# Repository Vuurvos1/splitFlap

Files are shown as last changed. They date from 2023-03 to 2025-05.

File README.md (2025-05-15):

<h1 align="center">SplitFlap</h1>

<p align="center">
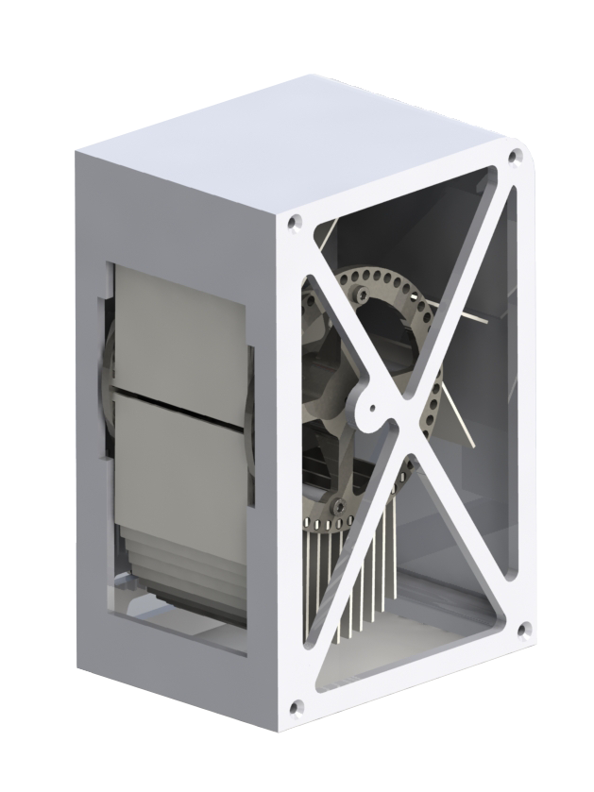
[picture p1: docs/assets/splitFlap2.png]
Split flap module
  
</p>

<p align="center">A modernized split flap display.</p>

## Features

- 50 Flaps per module
- 54mm x 80mm Character size
- Compact 80mm x 160mm x 110mm module size
- 3D printable
- Daisy chained
- Web controllabe

## Dashboard

The display can be controlled through a web dashboard hosted on the controller module.

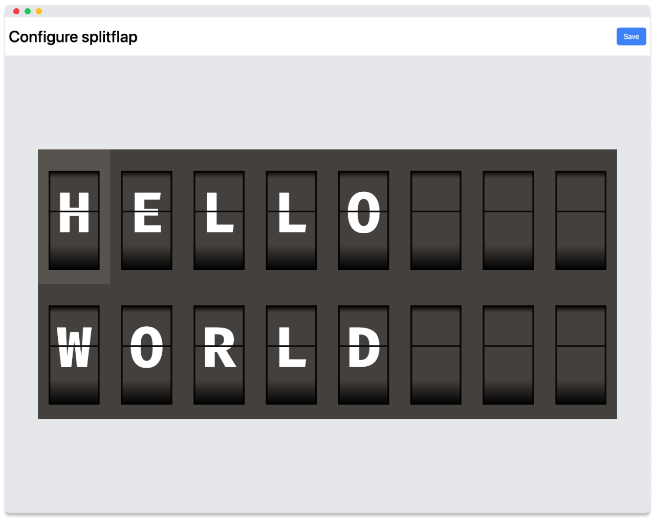
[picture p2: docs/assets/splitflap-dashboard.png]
Dashboard


## Flap Characters

Suggested 50 characters:

```
A B C D E F G H I J K L M N O P Q R S T U V W X Y Z (26)
1 2 3 4 5 6 7 8 9 0 (10)
blank □ full ■ (2)
? ! + - = * ' : , . @ # % € (14)
```

 <!-- $ & ^ ; -->

> [!NOTE]  
> `0 O` and `1 I` can share the same flap

## Materials

- 1x Nema 17 Stepper Motor
- 1x A4988 Stepper Motor Driver (or similar)
- 1x Hall Effect Switch (a TLE4905L or similar)
- 8x M3 Countersunk Screws (for the body)
- 8x M3 Screws (for the barrel)
- 4x M3x18 Screws (to mount the motor)
- 1x M3 Countersunk Screw (for the flap stopper)

### Micro controller

- Esp32
- Arduino pro micro

I am using an Esp32 for the main module, and you can use any other micro controller like a pro micro for the other modules.

### Motor

I originally got dual shafted Nema 17 motors for this project so I could mount the flap barrel on the back side of the motor.

> [!NOTE]  
> You could use any other Nema 17 motor with a reversed D shaft.
> Reversing the shaft can easily be done if you open up the motor and flip the shaft so it sticks out of the "back" of the motor.
> You might need to tweak the motor spacers and use different length screws to mount different motors.

### Driver

- A4988 Stepper Motor Driver

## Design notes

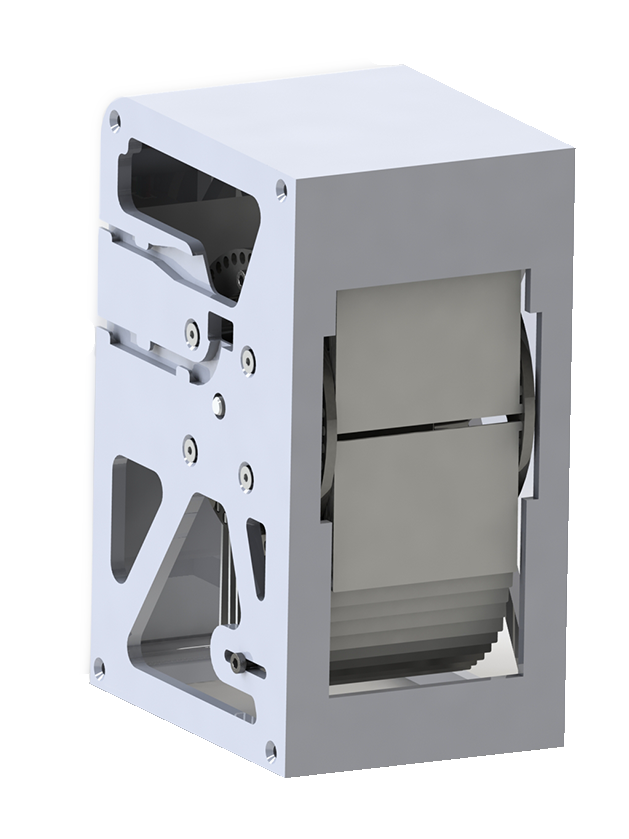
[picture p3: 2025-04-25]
docs/assets/splitFlap1.png

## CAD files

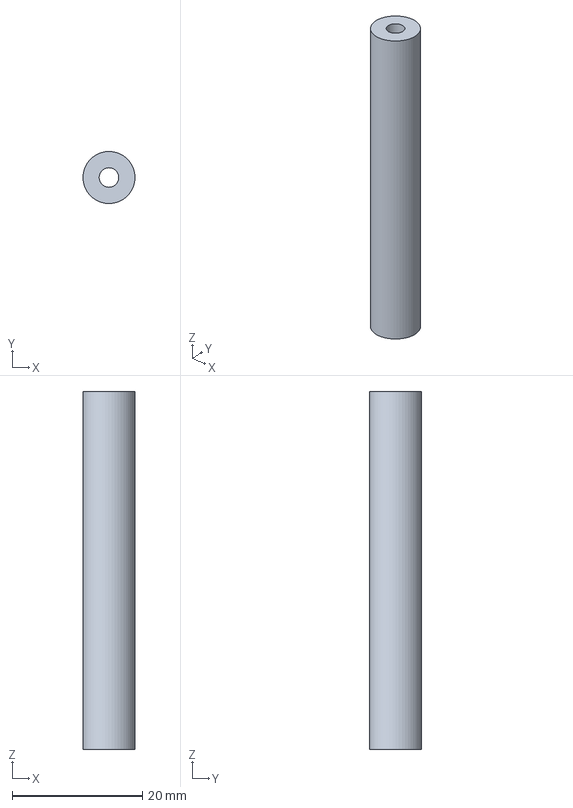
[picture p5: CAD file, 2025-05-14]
cad/barrel/barrelSpacer.FCStd
7.99 x 8.00 x 55.0 mm

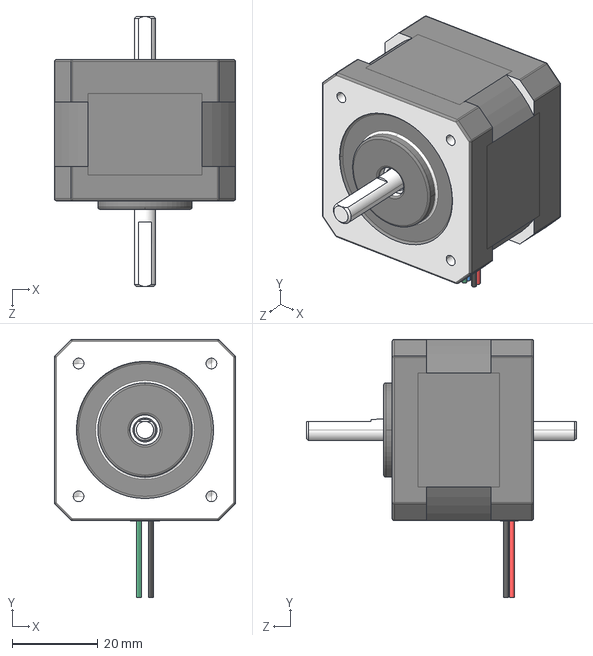
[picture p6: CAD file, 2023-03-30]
cad/hardware/17HS13-0404D.STEP
42.3 x 60.3 x 63.0 mm

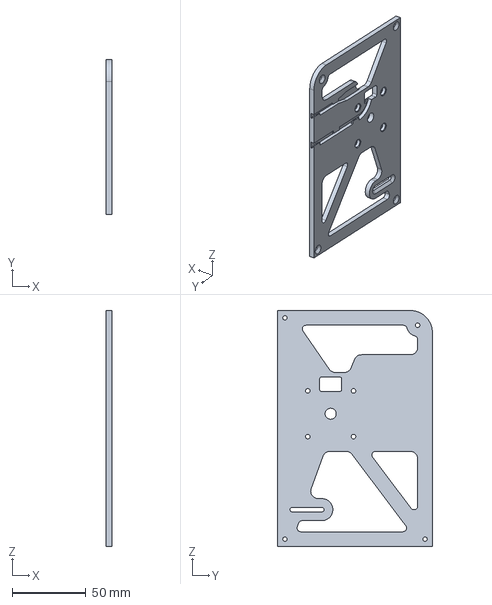
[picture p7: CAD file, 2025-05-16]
cad/sideMotor.FCStd
4.00 x 105.0 x 160.0 mm

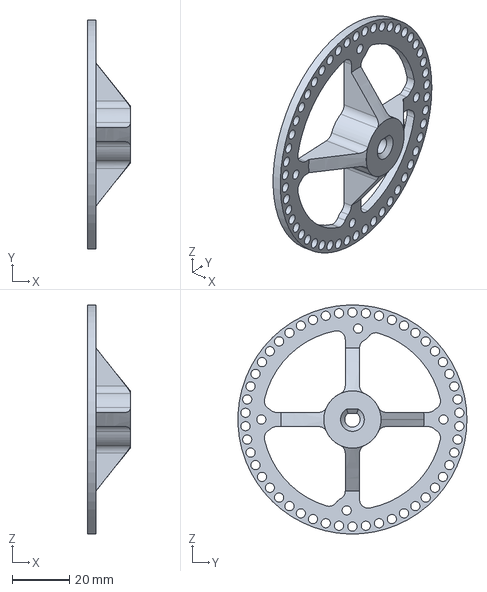
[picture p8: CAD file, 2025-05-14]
cad/barrel/barrelMount.FCStd
15.0 x 79.9 x 80.0 mm

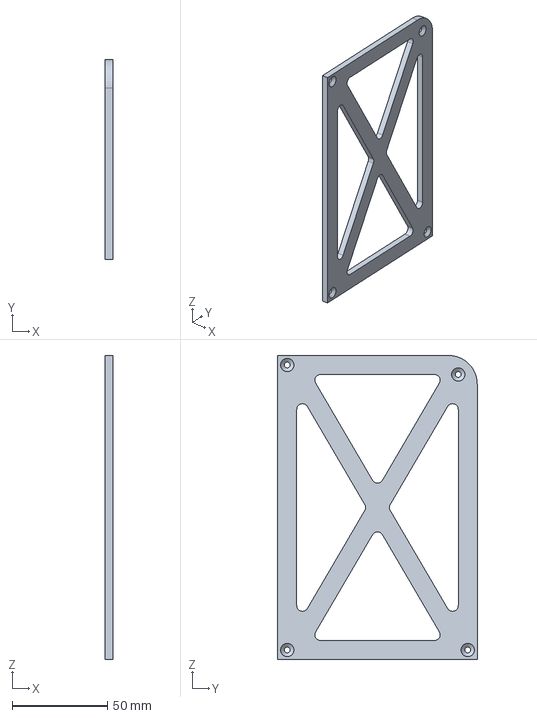
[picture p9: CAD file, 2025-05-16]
cad/sideLeft.FCStd
4.00 x 105.0 x 160.0 mm

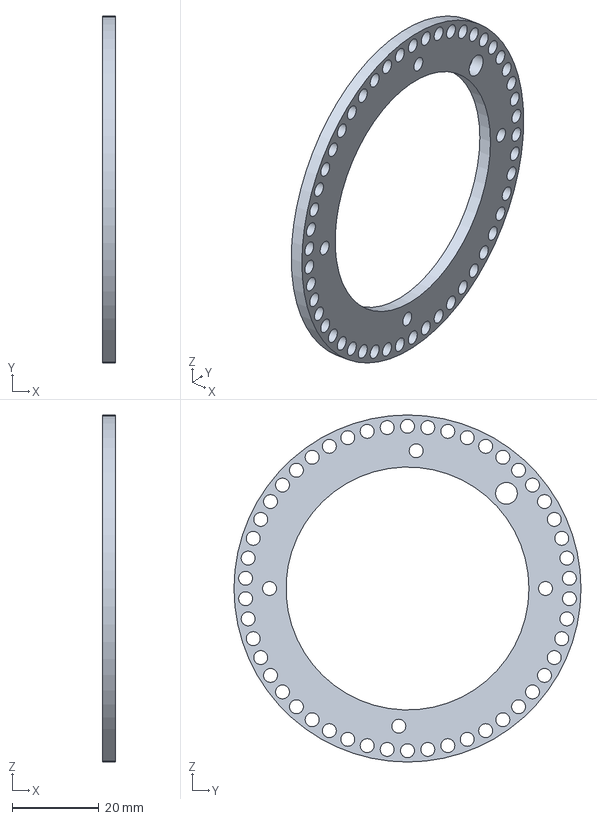
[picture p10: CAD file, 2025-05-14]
cad/barrel/barrelSideOpen.FCStd
3.00 x 80.0 x 80.0 mm

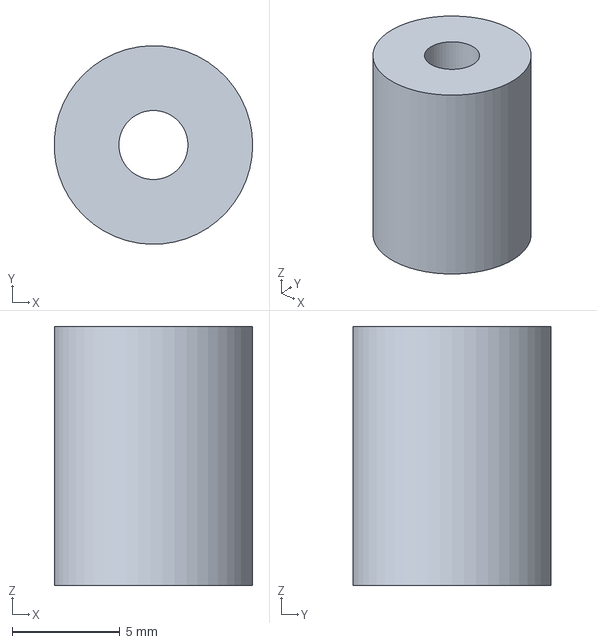
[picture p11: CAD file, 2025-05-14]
cad/motorSpacer.FCStd
9.19 x 9.20 x 12.0 mm

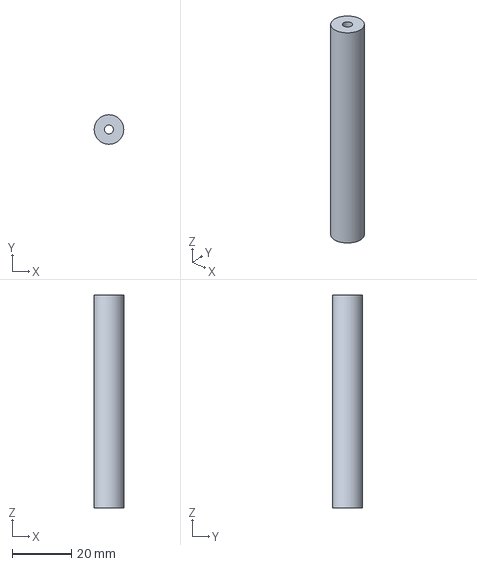
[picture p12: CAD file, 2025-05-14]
cad/bodySpacer.FCStd
9.99 x 10.00 x 72.0 mm

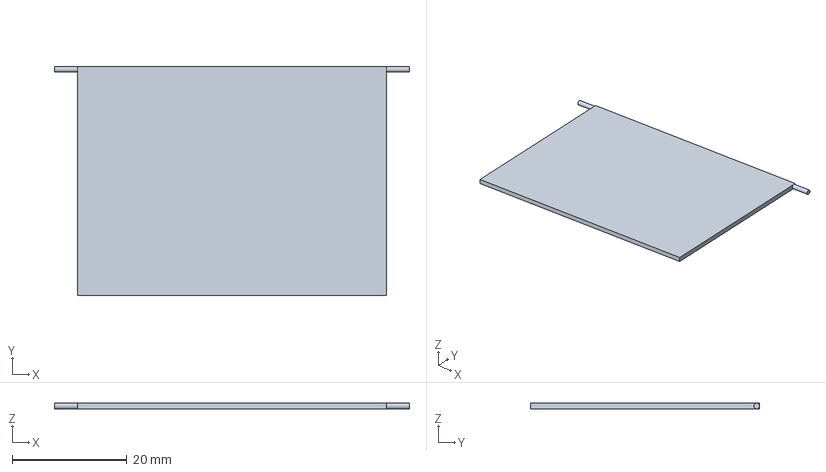
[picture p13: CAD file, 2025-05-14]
cad/roundFlap.FCStd
62.0 x 40.0 x 1.00 mm

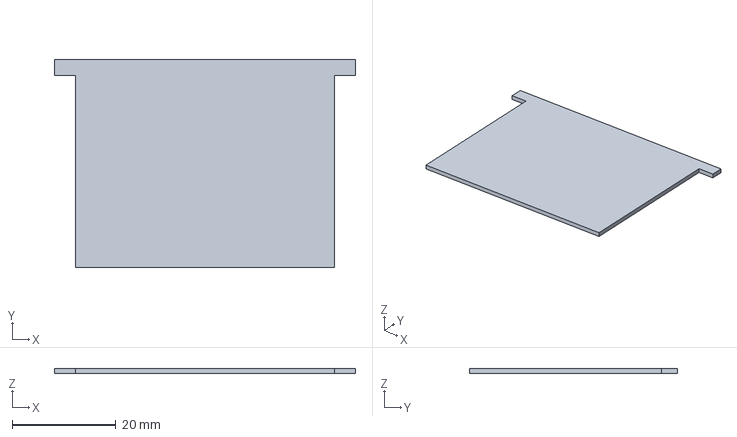
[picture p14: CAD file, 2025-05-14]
cad/flap.FCStd
58.0 x 40.0 x 1.00 mm

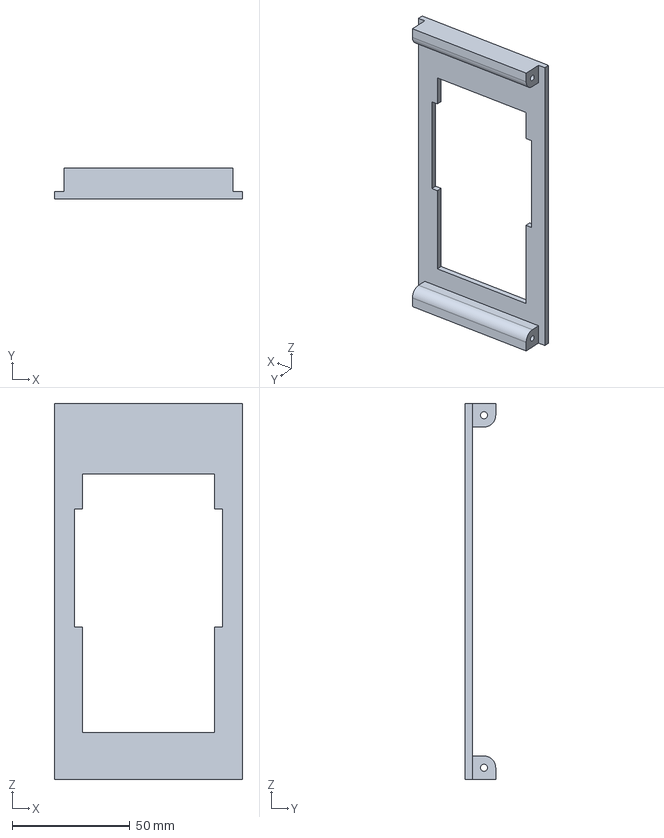
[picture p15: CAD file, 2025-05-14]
cad/front.FCStd
80.0 x 13.0 x 160.0 mm

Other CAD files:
cad/splitflap.FCStd
cad/barrel/barrel.FCStd
cad/hardware/17HS13-0404D.FCStd

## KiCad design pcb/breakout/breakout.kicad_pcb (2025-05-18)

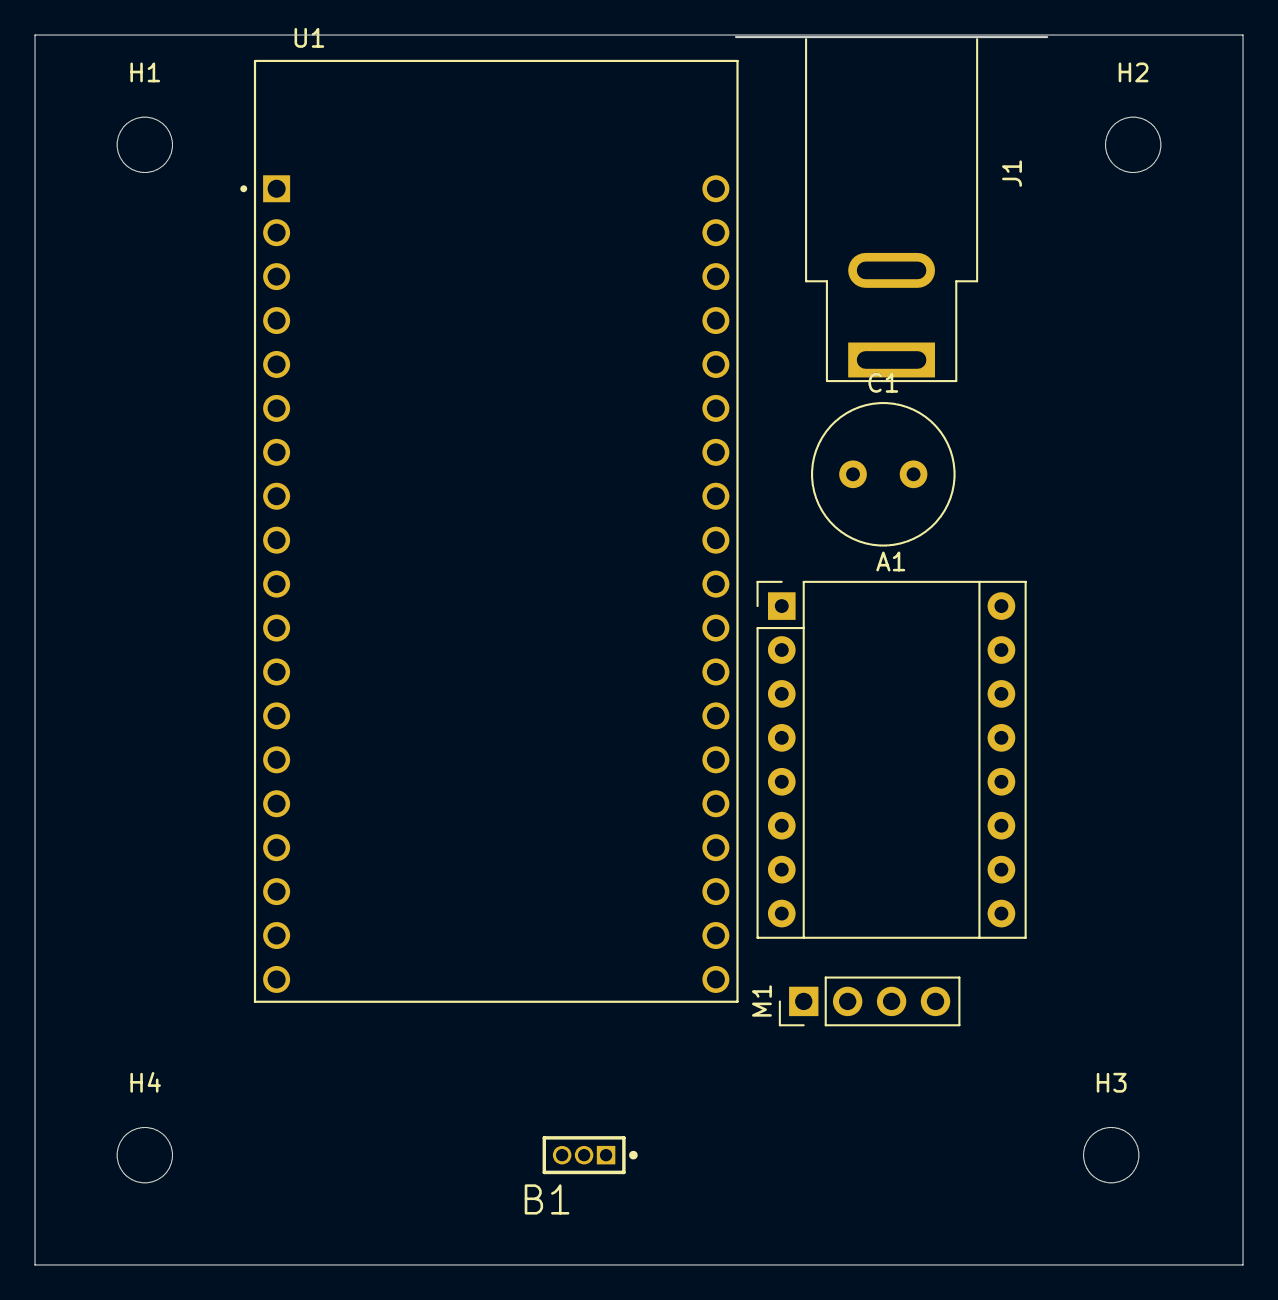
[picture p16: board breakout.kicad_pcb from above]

Board: 2 copper layers, 69.9 x 71.1 mm, 10 parts (0 on the bottom side), 12 nets, no tracks yet.

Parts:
A1: Pololu_Breakout_A4988; Pololu_Breakout-16_15.2x20.3mm
B1: TLE4905L; IFX-PG-SSO-3-2
C1: 100uF; C_Radial_D8.0mm_H11.5mm_P3.50mm
H1, H2, H3, H4: MountingHole; MountingHole_3.2mm_M3
J1: Barrel_Jack; BarrelJack_SwitchcraftConxall_RAPC10U_Horizontal
M1: Stepper_Motor_bipolar; PinHeader_1x04_P2.54mm_Vertical
U1: ESP32-DEVKITC-32D; MODULE_ESP32-DEVKITC-32D

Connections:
+5V: A1.2 (VDD), A1.10 (MS1), A1.11 (MS2), A1.12 (MS3), B1.1 (VS)
+12V: A1.8 (VMOT), C1.1, J1.1
<NO NET>: A1.1 (GND), A1.7 (GND), C1.2, J1.2
D15: B1.3 (Q), U1.J3-16 (IO15)
D18: A1.15 (STEP), U1.J3-9 (IO18)
D19: A1.16 (DIR), U1.J3-8 (IO19)
GND: B1.2 (GND), U1.J2-14 (GND1), U1.J3-1 (GND3), U1.J3-7 (GND2)
unnamed: A1.4 (1A), M1.1
unnamed: A1.3 (1B), M1.2 (-)
unnamed: A1.5 (2A), M1.3
unnamed: A1.6 (2B), M1.4
unnamed: A1.13 (~RESET), A1.14 (~SLEEP)

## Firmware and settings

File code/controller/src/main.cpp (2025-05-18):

#include <Arduino.h>
#include <config.h>
#include <HardwareSerial.h>

#include <WiFi.h>
#include <WebServer.h>
#include <ESPmDNS.h>
#include <LittleFS.h>

#include <SplitFlap.h>
#include <utils.h>

#define TXD1 19
#define RXD1 21

// Use Serial1 for UART communication
HardwareSerial mySerial(1);

WebServer server(80);

// defines pins
#define STEP_PIN 16
#define DIR_PIN 17
#define HALL_PIN 15

SplitFlap splitFlap(STEP_PIN, DIR_PIN, HALL_PIN);

String getContentType(String filename)
{
  if (filename.endsWith(".html"))
    return "text/html";
  else if (filename.endsWith(".css"))
    return "text/css";
  else if (filename.endsWith(".js"))
    return "application/javascript";
  else if (filename.endsWith(".json"))
    return "application/json";
  else if (filename.endsWith(".png"))
    return "image/png";
  else if (filename.endsWith(".jpg"))
    return "image/jpeg";
  else if (filename.endsWith(".ico"))
    return "image/x-icon";
  else if (filename.endsWith(".svg"))
    return "image/svg+xml";
  else if (filename.endsWith(".woff2"))
    return "font/woff2";
  else if (filename.endsWith(".woff"))
    return "font/woff";
  else if (filename.endsWith(".ttf"))
    return "font/ttf";
  else if (filename.endsWith(".mp3"))
    return "audio/mpeg";
  else if (filename.endsWith(".mp4"))
    return "video/mp4";
  return "application/octet-stream";
}

bool handleFileRead(String path)
{
  if (path.endsWith("/"))
    path += "index.html";

  String contentType = getContentType(path);

  if (LittleFS.exists(path))
  {
    File file = LittleFS.open(path, "r");
    server.streamFile(file, contentType);
    file.close();
    return true;
  }
  return false;
}

void handleNotFound()
{
  if (!handleFileRead(server.uri()))
  {
    {
      // Fall back to index.html for client-side routing
      handleFileRead("/index.html");
    }

    // server.send(404, "text/plain", "Not found");
  }
}

void handleCharacter()
{
  if (server.hasArg("c"))
  {
    char c = server.arg("c")[0];
    splitFlap.setCharacter(c);
    server.send(200, "text/plain", "OK");
    return;
  }

  server.send(400, "text/plain", "Bad request");
}

void handleFlaps()
{
  if (server.hasArg("f"))
  {
    int f = server.arg("f").toInt();
    splitFlap.setFlap(f);
    server.send(200, "text/plain", "OK");
    return;
  }

  server.send(400, "text/plain", "Bad request");
}

void handleSplitflap()
{
  if (server.method() != HTTP_POST)
  {
    server.send(405, "text/plain", "Method Not Allowed");
    return;
  }

  String body = server.arg("plain");

  // Simple validation - must start with [ and end with ]
  if (body[0] != '[' || body[body.length() - 1] != ']')
  {
    server.send(400, "text/plain", "Invalid array format");
    return;
  }

  // Remove the brackets
  body = body.substring(1, body.length() - 1);

  std::vector<uint8_t> data;

  // Split string into numbers and add to data vector
  int start = 0;
  while (true)
  {
    int end = body.indexOf(',', start);
    bool isLast = (end == -1);
    if (isLast)
    {
      end = body.length();
    }

    String numStr = body.substring(start, end);
    numStr.trim();
    if (numStr.length() > 0)
    {
      data.push_back(static_cast<uint8_t>(numStr.toInt()));
    }

    if (isLast)
      break;
    start = end + 1;
  }

  // print the data
  Serial.print("Data: ");
  for (uint8_t byte : data)
  {
    Serial.print(byte);
    Serial.print(" ");
  }
  Serial.println();

  // set splitflap to the first data value
  splitFlap.setFlap(data[0]);
  data.erase(data.begin());

  // pass the rest of the data to the splitflap
  auto packet = createPacket(data);
  mySerial.write(packet.data(), packet.size());

  server.send(200, "text/plain", "OK");
}

void setup()
{
  Serial.begin(115200);
  mySerial.begin(9600, SERIAL_8N1, RXD1, TXD1); // UART setup

  Serial.println("ESP32 UART Transmitter");

  while (!Serial)
    ;

  if (!LittleFS.begin(true))
  {
    Serial.println("An error occurred while mounting LittleFS");
  }

  splitFlap.init();
  splitFlap.home();

  WiFi.begin(WIFI_SSID, WIFI_PASSWORD);
  Serial.println("Establishing connection to WiFi");

  while (WiFi.status() != WL_CONNECTED)
  {
    delay(1000);
    Serial.print(".");
  }
  Serial.print("Connected to network with IP address: ");
  Serial.println(WiFi.localIP());

  // Initialize mDNS
  if (!MDNS.begin("splitflap"))
  { // Set the hostname to "splitflap.local"
    Serial.println("Error setting up MDNS responder!");
    while (1)
    {
      delay(1000);
    }
  }
  Serial.println("mDNS responder started");

  // server.on("/character", handleCharacter);
  server.on("/api/splitflap", handleSplitflap);
  server.on("/flaps", handleFlaps);
  server.onNotFound(handleNotFound);

  server.begin();
  Serial.println("HTTP server started");
}

void loop()
{
  splitFlap.update();
  server.handleClient();
}

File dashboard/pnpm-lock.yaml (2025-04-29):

lockfileVersion: '9.0'

settings:
  autoInstallPeers: true
  excludeLinksFromLockfile: false

importers:

  .:
    dependencies:
      '@fontsource/fira-mono':
        specifier: ^5.2.5
        version: 5.2.5
      '@unocss/reset':
        specifier: 66.1.0-beta.12
        version: 66.1.0-beta.12
    devDependencies:
      '@eslint/compat':
        specifier: ^1.2.5
        version: 1.2.8(eslint@9.25.1(jiti@2.4.2))
      '@eslint/js':
        specifier: ^9.18.0
        version: 9.25.1
      '@sveltejs/adapter-auto':
        specifier: ^6.0.0
        version: 6.0.0(@sveltejs/kit@2.20.7(@sveltejs/vite-plugin-svelte@5.0.3(svelte@5.28.2)(vite@6.3.3(jiti@2.4.2)))(svelte@5.28.2)(vite@6.3.3(jiti@2.4.2)))
      '@sveltejs/adapter-static':
        specifier: ^3.0.8
        version: 3.0.8(@sveltejs/kit@2.20.7(@sveltejs/vite-plugin-svelte@5.0.3(svelte@5.28.2)(vite@6.3.3(jiti@2.4.2)))(svelte@5.28.2)(vite@6.3.3(jiti@2.4.2)))
      '@sveltejs/kit':
        specifier: ^2.16.0
        version: 2.20.7(@sveltejs/vite-plugin-svelte@5.0.3(svelte@5.28.2)(vite@6.3.3(jiti@2.4.2)))(svelte@5.28.2)(vite@6.3.3(jiti@2.4.2))
      '@sveltejs/vite-plugin-svelte':
        specifier: ^5.0.0
        version: 5.0.3(svelte@5.28.2)(vite@6.3.3(jiti@2.4.2))
      '@unocss/extractor-svelte':
        specifier: 66.1.0-beta.12
        version: 66.1.0-beta.12
      eslint:
        specifier: ^9.18.0
        version: 9.25.1(jiti@2.4.2)
      eslint-config-prettier:
        specifier: ^10.0.1
        version: 10.1.2(eslint@9.25.1(jiti@2.4.2))
      eslint-plugin-svelte:
        specifier: ^3.0.0
        version: 3.5.1(eslint@9.25.1(jiti@2.4.2))(svelte@5.28.2)
      globals:
        specifier: ^16.0.0
        version: 16.0.0
      prettier:
        specifier: ^3.4.2
        version: 3.5.3
      prettier-plugin-svelte:
        specifier: ^3.3.3
        version: 3.3.3(prettier@3.5.3)(svelte@5.28.2)
      svelte:
        specifier: ^5.0.0
        version: 5.28.2
      svelte-check:
        specifier: ^4.0.0
        version: 4.1.6(picomatch@4.0.2)(svelte@5.28.2)(typescript@5.8.3)
      typescript:
        specifier: ^5.0.0
        version: 5.8.3
      typescript-eslint:
        specifier: ^8.20.0
        version: 8.31.0(eslint@9.25.1(jiti@2.4.2))(typescript@5.8.3)
      unocss:
        specifier: 66.1.0-beta.12
        version: 66.1.0-beta.12(postcss@8.5.3)(vite@6.3.3(jiti@2.4.2))(vue@3.5.13(typescript@5.8.3))
      vite:
        specifier: ^6.2.6
        version: 6.3.3(jiti@2.4.2)

packages:

  '@ampproject/remapping@2.3.0':
    resolution: {integrity: sha512-30iZtAPgz+LTIYoeivqYo853f02jBYSd5uGnGpkFV0M3xOt9aN73erkgYAmZU43x4VfqcnLxW9Kpg3R5LC4YYw==}
    engines: {node: '>=6.0.0'}

  '@antfu/install-pkg@1.0.0':
    resolution: {integrity: sha512-xvX6P/lo1B3ej0OsaErAjqgFYzYVcJpamjLAFLYh9vRJngBrMoUG7aVnrGTeqM7yxbyTD5p3F2+0/QUEh8Vzhw==}

  '@antfu/utils@8.1.1':
    resolution: {integrity: sha512-Mex9nXf9vR6AhcXmMrlz/HVgYYZpVGJ6YlPgwl7UnaFpnshXs6EK/oa5Gpf3CzENMjkvEx2tQtntGnb7UtSTOQ==}

  '@babel/helper-string-parser@7.25.9':
    resolution: {integrity: sha512-4A/SCr/2KLd5jrtOMFzaKjVtAei3+2r/NChoBNoZ3EyP/+GlhoaEGoWOZUmFmoITP7zOJyHIMm+DYRd8o3PvHA==}
    engines: {node: '>=6.9.0'}

  '@babel/helper-validator-identifier@7.25.9':
    resolution: {integrity: sha512-Ed61U6XJc3CVRfkERJWDz4dJwKe7iLmmJsbOGu9wSloNSFttHV0I8g6UAgb7qnK5ly5bGLPd4oXZlxCdANBOWQ==}
    engines: {node: '>=6.9.0'}

  '@babel/parser@7.27.0':
    resolution: {integrity: sha512-iaepho73/2Pz7w2eMS0Q5f83+0RKI7i4xmiYeBmDzfRVbQtTOG7Ts0S4HzJVsTMGI9keU8rNfuZr8DKfSt7Yyg==}
    engines: {node: '>=6.0.0'}
    hasBin: true

  '@babel/types@7.27.0':
    resolution: {integrity: sha512-H45s8fVLYjbhFH62dIJ3WtmJ6RSPt/3DRO0ZcT2SUiYiQyz3BLVb9ADEnLl91m74aQPS3AzzeajZHYOalWe3bg==}
    engines: {node: '>=6.9.0'}

  '@esbuild/aix-ppc64@0.25.3':
    resolution: {integrity: sha512-W8bFfPA8DowP8l//sxjJLSLkD8iEjMc7cBVyP+u4cEv9sM7mdUCkgsj+t0n/BWPFtv7WWCN5Yzj0N6FJNUUqBQ==}
    engines: {node: '>=18'}
    cpu: [ppc64]
    os: [aix]

  '@esbuild/android-arm64@0.25.3':
    resolution: {integrity: sha512-XelR6MzjlZuBM4f5z2IQHK6LkK34Cvv6Rj2EntER3lwCBFdg6h2lKbtRjpTTsdEjD/WSe1q8UyPBXP1x3i/wYQ==}
    engines: {node: '>=18'}
    cpu: [arm64]
    os: [android]

  '@esbuild/android-arm@0.25.3':
    resolution: {integrity: sha512-PuwVXbnP87Tcff5I9ngV0lmiSu40xw1At6i3GsU77U7cjDDB4s0X2cyFuBiDa1SBk9DnvWwnGvVaGBqoFWPb7A==}
    engines: {node: '>=18'}
    cpu: [arm]
    os: [android]

  '@esbuild/android-x64@0.25.3':
    resolution: {integrity: sha512-ogtTpYHT/g1GWS/zKM0cc/tIebFjm1F9Aw1boQ2Y0eUQ+J89d0jFY//s9ei9jVIlkYi8AfOjiixcLJSGNSOAdQ==}
    engines: {node: '>=18'}
    cpu: [x64]
    os: [android]

  '@esbuild/darwin-arm64@0.25.3':
    resolution: {integrity: sha512-eESK5yfPNTqpAmDfFWNsOhmIOaQA59tAcF/EfYvo5/QWQCzXn5iUSOnqt3ra3UdzBv073ykTtmeLJZGt3HhA+w==}
    engines: {node: '>=18'}
    cpu: [arm64]
    os: [darwin]
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

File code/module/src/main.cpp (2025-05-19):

#include <Arduino.h>
#include "utils.h"
#include <vector>
#include "SplitFlap.h"

#define TXD1 19
#define RXD1 21

// defines pins
#define STEP_PIN 16
#define DIR_PIN 17
#define HALL_PIN 15

SplitFlap splitFlap(STEP_PIN, DIR_PIN, HALL_PIN);

// Use Serial1 for UART communication
HardwareSerial mySerial(2);

bool readingPacket = false;

void handleMyByte(uint8_t byte)
{
  Serial.println("Received byte: " + String(byte));
  splitFlap.setFlap(byte);
}

void setup()
{
  Serial.begin(115200);
  mySerial.begin(9600, SERIAL_8N1, RXD1, TXD1); // UART setup

  splitFlap.init();
  splitFlap.home();

  Serial.println("Module started");
}

uint8_t flapIndex = 40;

void loop()
{
  splitFlap.update();

  // Check if data is available to read
  if (mySerial.available())
  {
    uint8_t incoming = mySerial.read();

    if (!readingPacket && incoming != END_BYTE)
    {
      readingPacket = true;
      handleMyByte(incoming);
    }
    else
    {
      // forward the data
      Serial.print(String(incoming) + " ");
      mySerial.write(incoming);
    }

    if (incoming == END_BYTE)
    {
      Serial.println("End of packet");
      readingPacket = false;
    }
  }
}

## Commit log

2021-05-05 Tweaking barrel
    [barrel.SLDASM, circleMount.SLDPRT, circleOpen.SLDPRT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]
2021-05-15 body and barrel tab
    [TestCircle.SLDPRT, barrel.SLDASM, blockingTab.SLDPRT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]
2021-05-22 Barrel tweaking
    [barrel.SLDASM, circleOpen.SLDPRT, motorConnectorThicc.SLDPRT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]
2021-05-23 Barrel width reduction
    [barrel.SLDASM, blockingTab.SLDPRT, circleMount.SLDPRT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]
2021-05-29 Reworking assemblies and constraints
    Reworked constraints and assemblies, also tweaked barrel width to be a bit smaller so flaps don't fall out
    [barrel.SLDASM, circleMount.SLDPRT, flap.SLDPRT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]
2021-12-06 Beefing up barrel and tweeking sizes
    [barrel.SLDASM, circleMount.SLDPRT, circleOpen.SLDPRT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]
2021-12-07 Rebuild and add possible special characters
    [barrel.SLDASM, circleOpen.SLDPRT, splitFlap.SLDASM]
2021-12-13 tweak barrel tolerances
    [barrel.SLDASM, circleMount.SLDPRT, flap.SLDPRT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]
2023-03-20 back mount motor
    [motorBackSpacer.SLDPRT, nema17.SLDPRT]
2023-03-20 screwify barrel side
    [barrelRoundSpacer.SLDPRT, circleMount.SLDPRT]
2023-03-21 change motor mounting
    [barrelRoundSpacer.SLDPRT, circleMount.SLDPRT, circleOpen.SLDPRT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]
2023-03-21 update assemblies
    [barrel.SLDASM, front.SLDPRT, splitFlap.SLDASM]
2023-03-26 update mounting
    [barrel.SLDASM, barrelRoundSpacer.SLDPRT, circleOpen.SLDPRT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]
2023-03-27 update barrel holes
    [barrel.SLDASM, circleMount.SLDPRT, circleOpen.SLDPRT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]
2023-03-29 updating to new stepper motor
    [barrel.SLDASM, barrelRoundSpacer.SLDPRT, front.SLDPRT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]
2023-03-30 adding bolts
    [17HS13-0404D.STEP, 17HS13-0404D1.SLDPRT, barrel.SLDASM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]
2023-04-03 update readme and add possible stepper libraries
2023-04-05 make stepper do turn
2024-05-09 working on module body
    [backPanel.SLDPRT, barrel.SLDASM, circleMount.SLDPRT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]
2024-05-14 working on body
    [backPanel.SLDPRT, barrel.SLDASM, barrelRoundSpacer.SLDPRT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]
2024-05-14 Making motors turn
2024-05-19 winder thing
    [diodeWinder.SLDPRT]
2024-05-19 use accell stepper lib
2024-06-19 upper case characters
2025-04-12 remove file
    [diodeWinder.SLDPRT]
2025-04-13 share data over uart
2025-04-16 tweaking models
    [barrel.SLDASM, circleMount.SLDPRT, motorBackSpacer.SLDPRT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]
2025-04-17 file cleaning
    [barrel.SLDASM, blockingTab.SLDPRT, card.SLDPRT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]
2025-04-22 update model
    [barrel.SLDASM, circleOpen.SLDPRT, motorBackSpacer.SLDPRT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]
2025-04-22 basic homing and testing logic
2025-04-25 improve homing logic
2025-04-25 fix: homing logic and set flap overflow
    [SplitFlap.h, main.cpp]
2025-04-26 try out freecad
    [front.FCStd]
2025-05-03 update cad
    [barrel.FCStd, barrelMount.FCStd, barrelSideOpen.FCStd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]
2025-05-04 improve modeling
    [barrel.FCStd, barrelMount.FCStd, barrelSideOpen.FCStd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]
2025-05-12 remove old cad files
    [17HS13-0404D.STEP, 17HS13-0404D1.SLDPRT, StepMotor v11.SLDASM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]
2025-05-14 fix: exploded assembly
    [17HS13-0404D.FCStd, 17HS13-0404D.STEP, barrel.FCStd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]
2025-05-14 improve side cable routing
    [front.FCStd, sideLeft.FCStd, sideMotor.FCStd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]
2025-05-16 tweak side chamfers and routing
    [sideLeft.FCStd, sideMotor.FCStd, splitflap.FCStd]
2025-05-18 add wireing schematic
    [breakout.kicad_pcb, breakout.kicad_sch]
